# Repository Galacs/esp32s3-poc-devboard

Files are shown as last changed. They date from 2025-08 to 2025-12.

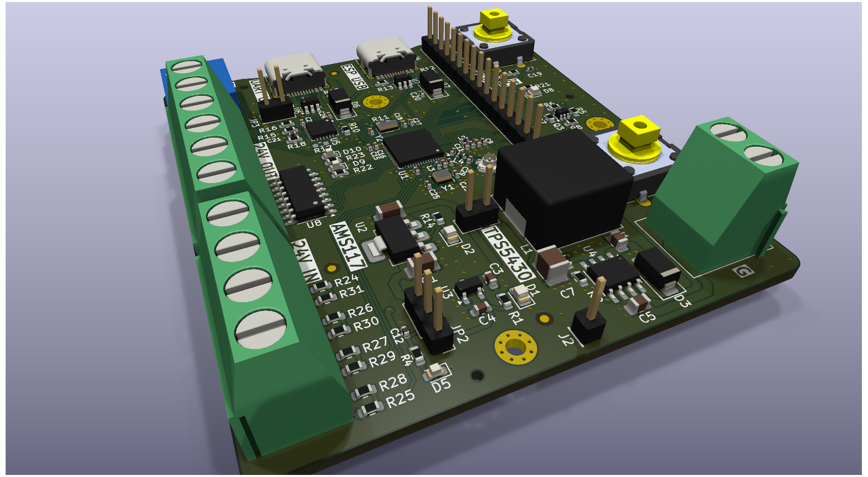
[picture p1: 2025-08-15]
docs/esp32s3-poc-devboard-render.png

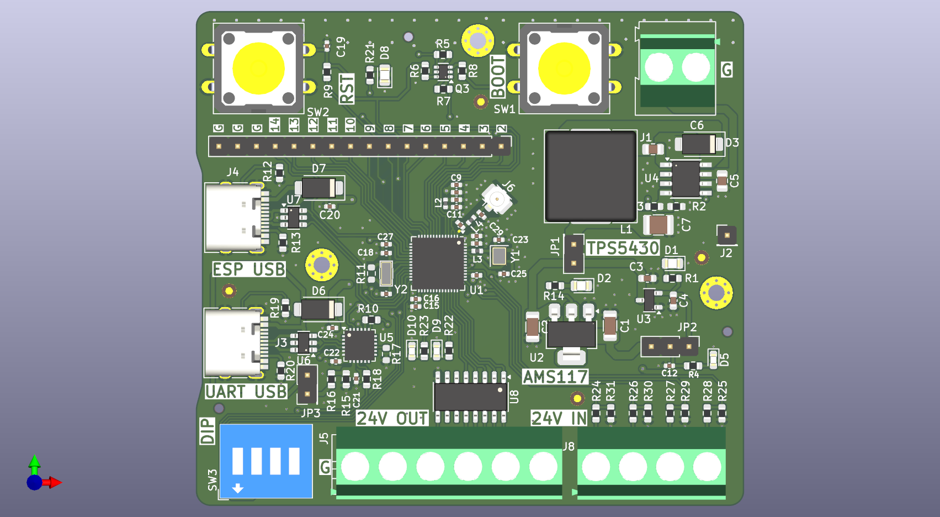
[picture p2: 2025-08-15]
docs/esp32s3-poc-devboard-top.png

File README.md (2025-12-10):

# ESP32-S3 POC/Devboard

ESP32-S3 based PoC board made to test step-down power supply design, 24v level shifter, crystal circuits and RF circuit

## IC List

- ESP32-S3Fx (main MCU)
- CP2102 (USB to UART)
- TPS5430 (step-down converter)
- AP2112K & XC6206 (3v3 LDOs)
- ULN2003A (transistor array)

## Top preview

esp32s3-poc-devboard-top

## Preview 3d render

esp32s3-poc-devboard-render

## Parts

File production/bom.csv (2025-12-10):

Designator | Footprint | Quantity | Value | LCSC Part #
C10, C11, C16, C17, C18 | 0402 | 5 | 0u1 | C307331
C12, C20, C22, C24, C8 | 0402 | 5 | 10u | C15525
C13 | 0402 | 1 | 10n | C15195
C14, C15, C19, C9 | 0402 | 4 | 1u | C52923
C21, C3, C30, C4 | 0603 | 4 | 1u | C15849
C23, C25 | 0402 | 2 | 12p | C1547
C26, C27 | 0402 | 2 | 20p | C1554
C28, C29 | 0402 | 2 | 1p2 | C76899
C5 | 0805 | 1 | 10u | C440198
C6 | 0805 | 1 | 10n | C1710
C7 | 1206 | 1 | 47u | C96123
D1, D2, D8 | 0805 | 3 | GREEN | C2297
D10 | 0603 | 1 | RED | C2286
D11, D12, D13, D14 | D_SOD-123 | 4 | BZT52B3V3 | C19077392
D3, D6, D7 | D_SMA | 3 | D_Schottky | C22452
D5, D9 | 0603 | 2 | WHITE | C2290
J3, J4 | USB_C_Receptacle_HRO_TYPE-C-31-M-12 | 2 | USB_C_Receptacle_USB2.0_14P | C393939
J6 | U.FL_Hirose_U.FL-R-SMT-1_Vertical | 1 | Conn_Coaxial | C88374
L1 | L_SXN_SMDRI127 | 1 | 100u | C10150
L2, L4 | 0402 | 2 | 2n7 | C412269
L3 | 0402 | 1 | 24n | C167472
Q3 | SOT-363_SC-70-6 | 1 | MMDT5551 | C41375116
R1, R12, R13, R14, R19, R20, R21, R22, R23, R24, R26, R27, R28, R4 | 0603 | 14 | 5k1 | C23186
R10 | 0603 | 1 | 470 | C23179
R18 | 0603 | 1 | 1k | C21190
R2 | 0603 | 1 | 4k7 | C23162
R25, R29, R30, R31 | 0603 | 4 | 750 | C23241
R3, R5, R7, R9 | 0603 | 4 | 10k | C25804
R6, R8 | 0603 | 2 | 0 | C21189
U1 | QFN-56-1EP_7x7mm_P0.4mm_EP5.6x5.6mm | 1 | ESP32-S3FH4R2 | C3013940
U3 | SOT-23-3 | 1 | XC6206P332MR-G | C5446
U4 | TI_SO-PowerPAD-8_ThermalVias | 1 | TPS5430DDA | C9864
U5 | SOT-23-5 | 1 | AP2112K-3.3 | C51118
U6, U7 | SOT-23-6 | 2 | USBLC6-2SC6 | C7519
U8 | SOIC-16_3.9x9.9mm_P1.27mm | 1 | ULN2003A | C7512
U9 | QFN-28-1EP_5x5mm_P0.5mm_EP3.35x3.35mm | 1 | CP2102-GMR | C6568
Y1 | Crystal_SMD_2016-4Pin_2.0x1.6mm | 1 | 48M | C7206306
Y2 | Crystal_SMD_3215-2Pin_3.2x1.5mm | 1 | 32k768 | C32346

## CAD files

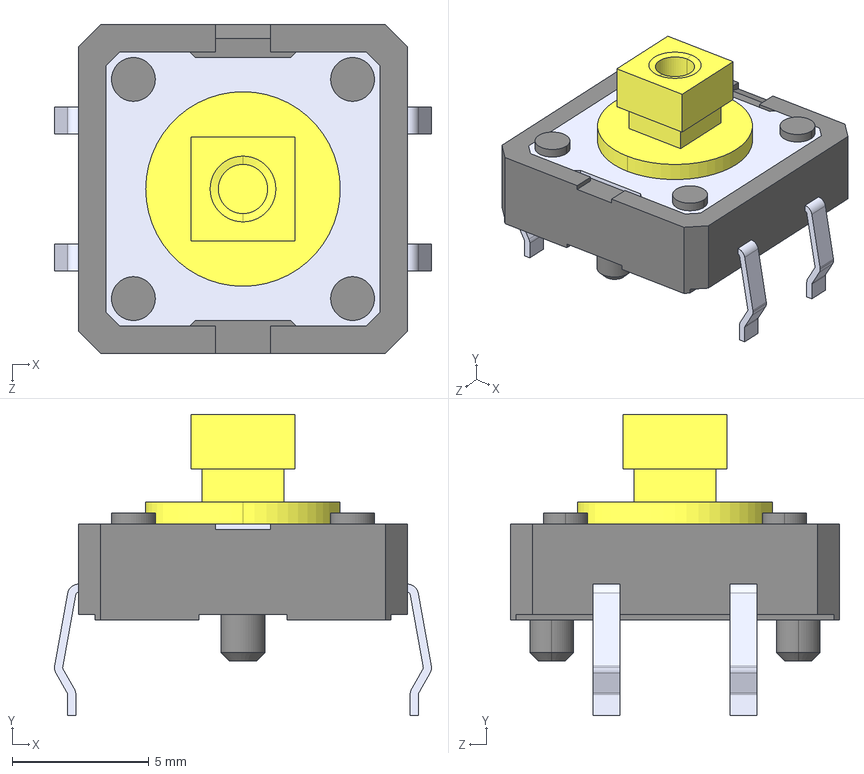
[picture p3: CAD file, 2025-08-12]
external_step/B3F-4055.STEP
13.8 x 11.0 x 12.0 mm

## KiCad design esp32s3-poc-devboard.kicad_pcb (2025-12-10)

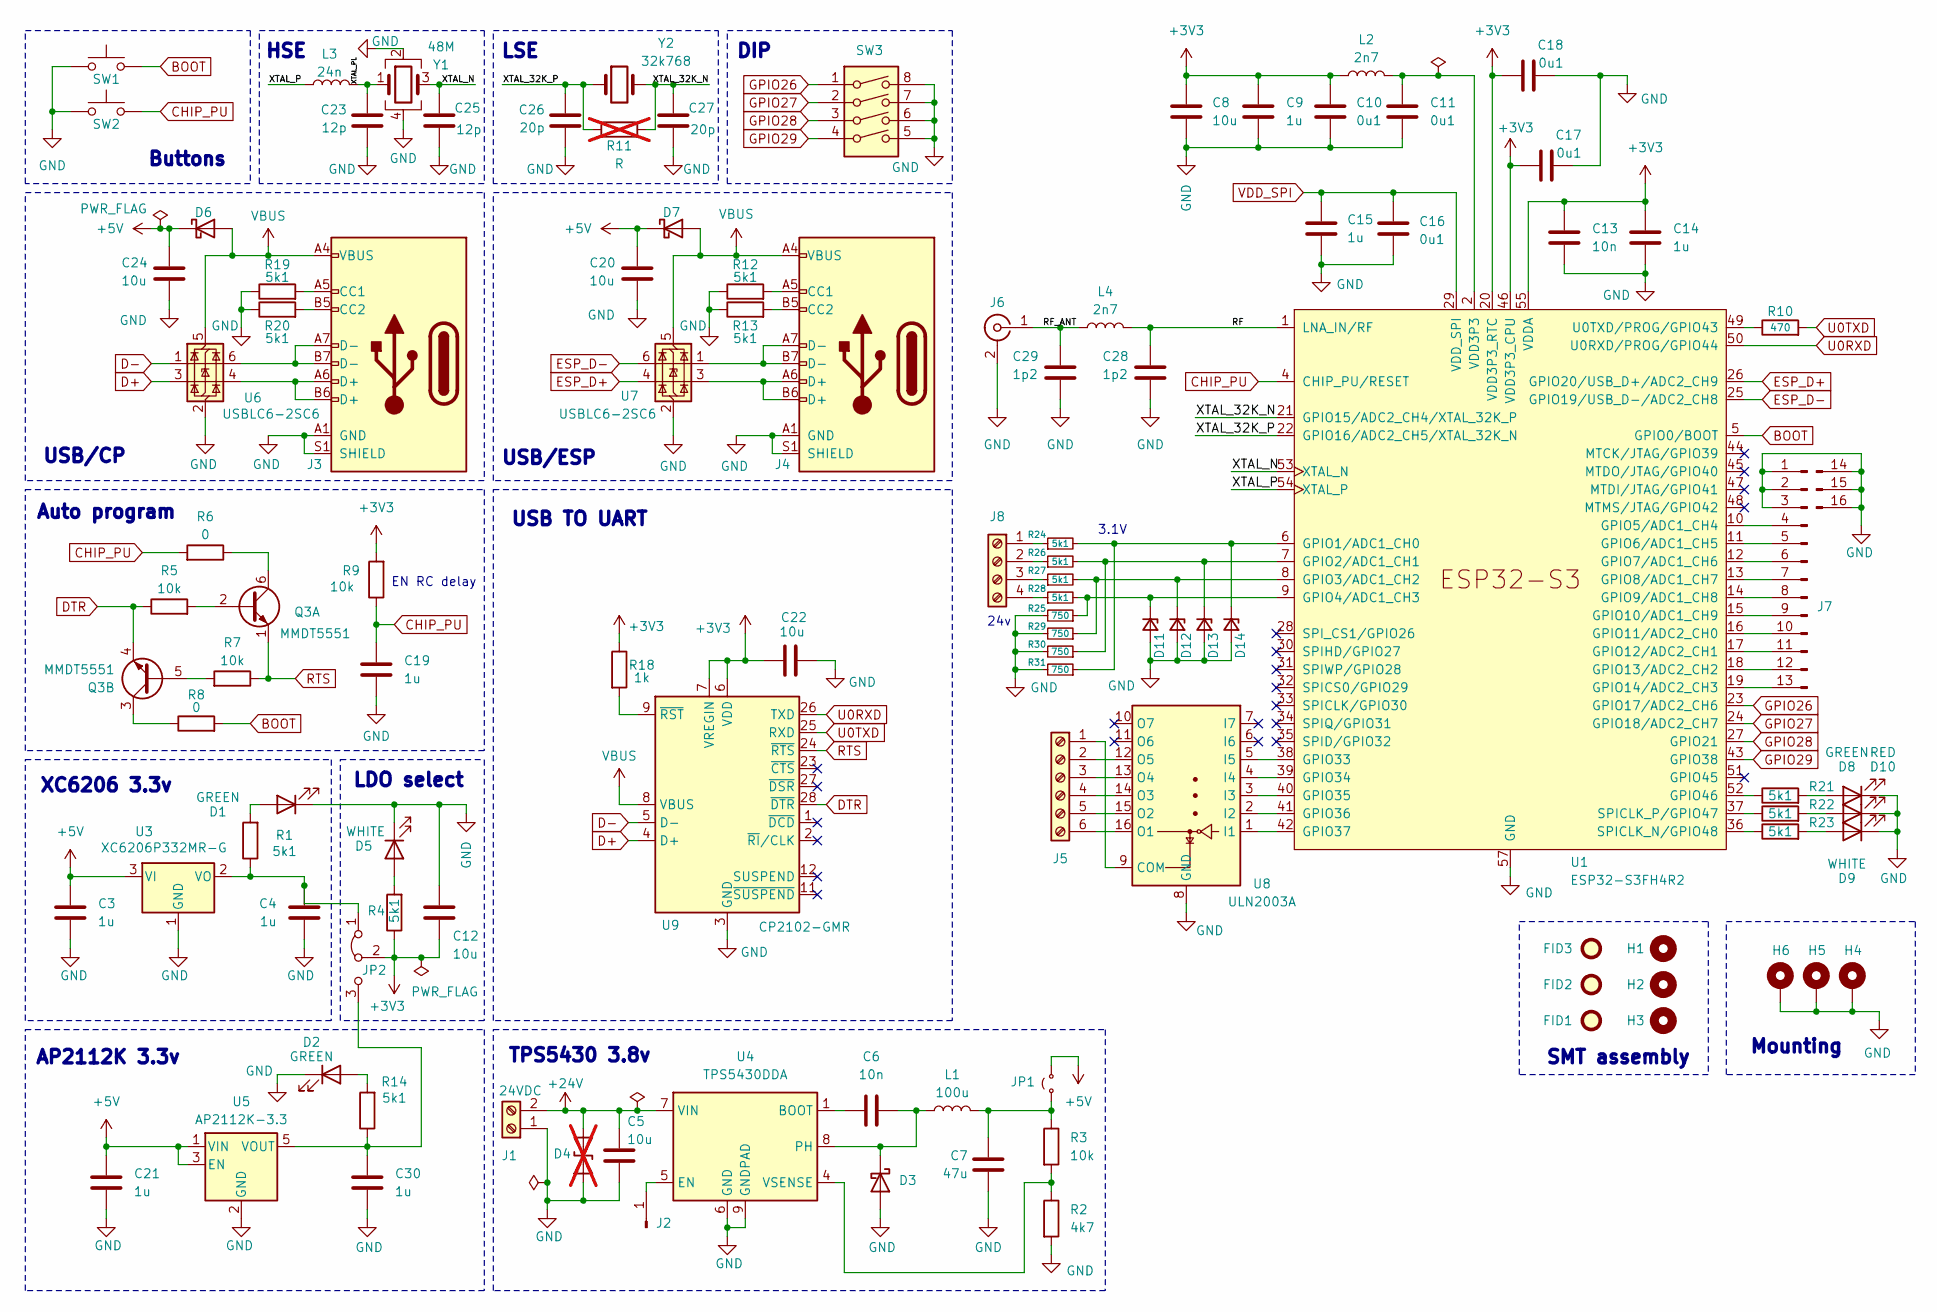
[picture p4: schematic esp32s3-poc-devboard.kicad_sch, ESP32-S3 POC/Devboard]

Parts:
C3, C4, C21, C30: 1u; C_0603_1608Metric; Manufacturer Part Number CL10A105KB8NNNC; JLCPCB Part # C15849
C5: 10u; C_0805_2012Metric; Manufacturer Part Number GRM21BR61H106KE43L; JLCPCB Part # C440198
C6: 10n; C_0805_2012Metric; Manufacturer Part Number CL21B103KBANNNC; JLCPCB Part # C1710
C7: 47u; C_1206_3216Metric; Manufacturer Part Number CL31A476MPHNNNE; JLCPCB Part # C96123
C8, C12, C20, C22, C24: 10u; C_0402_1005Metric; Manufacturer Part Number CL05A106MQ5NUNC; JLCPCB Part # C15525
C9, C14, C15, C19: 1u; C_0402_1005Metric; Manufacturer Part Number CL05A105KA5NQNC; JLCPCB Part # C52923
C10, C11, C16, C17, C18: 0u1; C_0402_1005Metric; Manufacturer Part Number CL05B104KB54PNC; JLCPCB Part # C307331
C13: 10n; C_0402_1005Metric; Manufacturer Part Number CL05B103KB5NNNC; JLCPCB Part # C15195
C23, C25: 12p; C_0402_1005Metric; Manufacturer Part Number 0402CG120J500NT; JLCPCB Part # C1547
C26, C27: 20p; C_0402_1005Metric; Manufacturer Part Number 0402CG200J500NT; JLCPCB Part # C1554
C28, C29: 1p2; C_0402_1005Metric; Manufacturer Part Number GJM1555C1H1R2WB01D; JLCPCB Part # C76899
D1, D2, D8: GREEN; LED_0805_2012Metric; Manufacturer Part Number KT-0805G; JLCPCB Part # C2297
D3, D6, D7: D_Schottky; D_SMA; Manufacturer Part Number SS54; JLCPCB Part # C22452
D4: D_TVS; not fitted
D5, D9: WHITE; LED_0603_1608Metric; Manufacturer Part Number KT-0603W; JLCPCB Part # C2290
D10: RED; LED_0603_1608Metric; Manufacturer Part Number KT-0603R; JLCPCB Part # C2286
D11, D12, D13, D14: BZT52B3V3; D_SOD-123; Manufacturer Part Number BZT52B3V3; JLCPCB Part # C19077392
FID1, FID2, FID3: Fiducial; Fiducial_1mm_Mask2mm
H1, H2, H3: MountingHole; ToolingHole_1.152mm
H4, H5, H6: MountingHole_Pad; MountingHole_2.2mm_M2_Pad_Via
J1: 24VDC; TerminalBlock_Altech_AK300-2_P5.00mm
J2: Conn_01x01_Pin; PinHeader_1x01_P2.54mm_Vertical
J3, J4: USB_C_Receptacle_USB2.0_14P; USB_C_Receptacle_HRO_TYPE-C-31-M-12; Manufacturer Part Number TYPE-C16PIN; JLCPCB Part # C393939
J5: Screw_Terminal_01x06; TerminalBlock_MaiXu_MX126-5.0-06P_1x06_P5.00mm
J6: Conn_Coaxial; U.FL_Hirose_U.FL-R-SMT-1_Vertical; Manufacturer Part Number U.FL-R-SMT-1(80); JLCPCB Part # C88374
J7: Conn_01x16_Pin; PinHeader_1x16_P2.54mm_Vertical
J8: Screw_Terminal_01x04; TerminalBlock_Altech_AK300-4_P5.00mm
JP1: Jumper_2_Small_Open; PinHeader_2x01_P2.54mm_Vertical
JP2: Jumper_3_Bridged12; PinHeader_1x03_P2.54mm_Vertical
L1: 100u; L_SXN_SMDRI127; Manufacturer Part Number SMDRI127-101MT; JLCPCB Part # C10150
L2, L4: 2n7; L_0402_1005Metric; Manufacturer Part Number LQW15AN2N7G80D; JLCPCB Part # C412269
L3: 24n; L_0402_1005Metric; Manufacturer Part Number LQW15AN24NG00D; JLCPCB Part # C167472
Q3: MMDT5551; SOT-363_SC-70-6; Manufacturer Part Number MMDT5551; JLCPCB Part # C41375116
R1, R4, R12, R13, R14, R19, R20, R21, R22, R23, R24, R26, R27, R28: 5k1; R_0603_1608Metric; Manufacturer Part Number 0603WAF5101T5E; JLCPCB Part # C23186
R2: 4k7; R_0603_1608Metric; Manufacturer Part Number 0603WAF4701T5E; JLCPCB Part # C23162
R3, R5, R7, R9: 10k; R_0603_1608Metric; Manufacturer Part Number 0603WAF1002T5E; JLCPCB Part # C25804
R6, R8: 0; R_0603_1608Metric; Manufacturer Part Number 0603WAF0000T5E; JLCPCB Part # C21189
R10: 470; R_0603_1608Metric; Manufacturer Part Number 0603WAF4700T5E; JLCPCB Part # C23179
R11: R; R_0603_1608Metric; not fitted
R18: 1k; R_0603_1608Metric; Manufacturer Part Number 0603WAF1001T5E; JLCPCB Part # C21190
R25, R29, R30, R31: 750; R_0603_1608Metric; Manufacturer Part Number 0603WAF7500T5E; JLCPCB Part # C23241
SW1, SW2: SW_Push; SW_SPST_Omron_B3F-40xx
SW3: SW_DIP_x04; SW_DIP_SPSTx04_Slide_9.78x12.34mm_W7.62mm_P2.54mm
U1: ESP32-S3FH4R2; QFN-56-1EP_7x7mm_P0.4mm_EP5.6x5.6mm; Manufacturer Part Number ESP32-S3FH4R2; JLCPCB Part # C3013940
U3: XC6206P332MR-G; SOT-23-3; Manufacturer Part Number XC6206P332MR-G; JLCPCB Part # C5446
U4: TPS5430DDA; TI_SO-PowerPAD-8_ThermalVias; Manufacturer Part Number TPS5430DDAR; JLCPCB Part # C9864
U5: AP2112K-3.3; SOT-23-5; Manufacturer Part Number AP2112K-3.3TRG1; JLCPCB Part # C51118
U6, U7: USBLC6-2SC6; SOT-23-6; Manufacturer Part Number USBLC6-2SC6; JLCPCB Part # C7519
U8: ULN2003A; SOIC-16_3.9x9.9mm_P1.27mm; Manufacturer Part Number ULN2003ADR; JLCPCB Part # C7512
U9: CP2102-GMR; QFN-28-1EP_5x5mm_P0.5mm_EP3.35x3.35mm; Manufacturer Part Number CP2102-GMR; JLCPCB Part # C6568
Y1: 48M; Crystal_SMD_2016-4Pin_2.0x1.6mm; Manufacturer Part Number R940000096; JLCPCB Part # C7206306
Y2: 32k768; Crystal_SMD_3215-2Pin_3.2x1.5mm; Manufacturer Part Number Q13FC13500004; JLCPCB Part # C32346

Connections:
+3V3: C8.1, C9.1, C10.1, C12.2, C13.1, C14.1, C17.1, C18.1, C22.2, JP2.2 (C), L2.1, R4.1, R9.2, R18.1, U1.20 (VDD3P3_RTC), U1.46 (VDD3P3_CPU), U1.55 (VDDA), U1.56 (VDDA), U9.6 (VDD), U9.7 (VREGIN)
+5V: C3.1, C20.1, C21.1, C24.1, D6.1 (K), D7.1 (K), JP1.2 (B), U3.3 (VI), U5.1 (VIN), U5.3 (EN)
+24V: C5.1, D4.2 (A2), J1.2, U4.7 (VIN)
/RF: C28.1, L4.2, U1.1 (LNA_IN/RF)
/RF_ANT: C29.1, J6.1 (In), L4.1
/XTAL_32K_N: C27.1, R11.2, U1.21 (GPIO15/ADC2_CH4/XTAL_32K_P), Y2.2
/XTAL_32K_P: C26.2, R11.1, U1.22 (GPIO16/ADC2_CH5/XTAL_32K_N), Y2.1
/XTAL_N: C25.1, U1.53 (XTAL_N), Y1.3
/XTAL_P: L3.1, U1.54 (XTAL_P)
/XTAL_PL: C23.2, L3.2, Y1.1
BOOT: R8.2, SW1.2, U1.5 (GPIO0/BOOT)
CHIP_PU: C19.1, R6.2, R9.1, SW2.2, U1.4 (CHIP_PU/RESET)
D+: U6.3 (I/O2), U9.4 (D+)
D-: U6.1 (I/O1), U9.5 (D-)
DTR: Q3.4 (E2), R5.1, U9.28 (~DTR)
ESP_D+: U1.26 (GPIO20/USB_D+/ADC2_CH9), U7.4 (I/O2)
ESP_D-: U1.25 (GPIO19/USB_D-/ADC2_CH8), U7.6 (I/O1)
GND: C3.2, C4.2, C5.2, C7.2, C8.2, C9.2, C10.2, C11.2, C12.1, C13.2, C14.2, C15.2, C16.2, C17.2, C18.2, C19.2, C20.2, C21.2, C22.1, C23.1, C24.2, C25.2, C26.1, C27.2, C28.2, C29.2, C30.2, D1.1 (K), D2.1 (K), D3.2 (A), D4.1 (A1), D5.1 (K), D8.1 (K), D9.1 (K), D10.1 (K), D11.2 (A), D12.2 (A), D13.2 (A), D14.2 (A), H4.1, H5.1, H6.1, J1.1, J3.A1 (GND), J3.A12 (GND), J3.B1 (GND), J3.B12 (GND), J3.S1 (SHIELD), J4.A1 (GND), J4.A12 (GND), J4.B1 (GND), J4.B12 (GND), J4.S1 (SHIELD), J6.2 (Ext), J7.1, J7.2, J7.3, J7.14, J7.15, J7.16, R2.2, R12.1, R13.1, R19.1, R20.1, R25.2, R29.2, R30.2, R31.2, SW1.1, SW2.1, SW3.5, SW3.6, SW3.7, SW3.8, U1.57 (GND), U3.1 (GND), U4.6 (GND), U4.9 (GNDPAD), U5.2 (GND), U6.2 (GND), U7.2 (GND), U8.8 (GND), U9.3 (GND), U9.29 (GND), Y1.2, Y1.4
GPIO26: SW3.1, U1.23 (GPIO17/ADC2_CH6)
GPIO27: SW3.2, U1.24 (GPIO18/ADC2_CH7)
GPIO28: SW3.3, U1.27 (GPIO21)
GPIO29: SW3.4, U1.43 (GPIO38)
unnamed: D1.2 (A), R1.2
unnamed: D2.2 (A), R14.2
unnamed: C6.1, D3.1 (K), L1.1, U4.8 (PH)
unnamed: D5.2 (A), R4.2
unnamed: D8.2 (A), R21.2
unnamed: D9.2 (A), R22.2
unnamed: D10.2 (A), R23.2
unnamed: D11.1 (K), R25.1, R28.2, U1.9 (GPIO4/ADC1_CH3)
unnamed: D12.1 (K), R27.2, R29.1, U1.8 (GPIO3/ADC1_CH2)
unnamed: D13.1 (K), R26.2, R30.1, U1.7 (GPIO2/ADC1_CH1)
unnamed: D14.1 (K), R24.2, R31.1, U1.6 (GPIO1/ADC1_CH0)
unnamed: J2.1, U4.5 (EN)
unnamed: J3.A5 (CC1), R19.2
unnamed: J3.B5 (CC2), R20.2
unnamed: J3.A6 (D+), J3.B6 (D+), U6.4 (I/O2)
unnamed: J3.A7 (D-), J3.B7 (D-), U6.6 (I/O1)
unnamed: J4.A5 (CC1), R12.2
unnamed: J4.B5 (CC2), R13.2
unnamed: J4.A6 (D+), J4.B6 (D+), U7.3 (I/O2)
unnamed: J4.A7 (D-), J4.B7 (D-), U7.1 (I/O1)
unnamed: J5.1, U8.9 (COM)
unnamed: J5.2, U8.12 (O5)
unnamed: J5.3, U8.13 (O4)
unnamed: J5.4, U8.14 (O3)
unnamed: J5.5, U8.15 (O2)
unnamed: J5.6, U8.16 (O1)
unnamed: J7.4, U1.10 (GPIO5/ADC1_CH4)
unnamed: J7.5, U1.11 (GPIO6/ADC1_CH5)
unnamed: J7.6, U1.12 (GPIO7/ADC1_CH6)
unnamed: J7.7, U1.13 (GPIO8/ADC1_CH7)
unnamed: J7.8, U1.14 (GPIO9/ADC1_CH8)
unnamed: J7.9, U1.15 (GPIO10/ADC1_CH9)
unnamed: J7.10, U1.16 (GPIO11/ADC2_CH0)
unnamed: J7.11, U1.17 (GPIO12/ADC2_CH1)
unnamed: J7.12, U1.18 (GPIO13/ADC2_CH2)
unnamed: J7.13, U1.19 (GPIO14/ADC2_CH3)
unnamed: J8.1, R24.1
unnamed: J8.2, R26.1
unnamed: J8.3, R27.1
unnamed: J8.4, R28.1
unnamed: C7.1, JP1.1 (A), L1.2, R3.1
unnamed: C4.1, JP2.1 (A), R1.1, U3.2 (VO)
unnamed: C30.1, JP2.3 (B), R14.1, U5.5 (VOUT)
unnamed: Q3.2 (B1), R5.2
unnamed: Q3.6 (C1), R6.1
unnamed: Q3.5 (B2), R7.2
unnamed: Q3.3 (C2), R8.1
unnamed: U1.38 (GPIO33), U8.5 (I5)
unnamed: U1.39 (GPIO34), U8.4 (I4)
unnamed: U1.40 (GPIO35), U8.3 (I3)
unnamed: U1.41 (GPIO36), U8.2 (I2)
unnamed: U1.42 (GPIO37), U8.1 (I1)
unnamed: R21.1, U1.52 (GPIO46)
unnamed: R23.1, U1.36 (SPICLK_N/GPIO48)
unnamed: R22.1, U1.37 (SPICLK_P/GPIO47)
unnamed: R10.1, U1.49 (U0TXD/PROG/GPIO43)
unnamed: C6.2, U4.1 (BOOT)
unnamed: R2.1, R3.2, U4.4 (VSENSE)
unnamed: R18.2, U9.9 (~RST)
RTS: Q3.1 (E1), R7.1, U9.24 (~RTS)
U0RXD: U1.50 (U0RXD/PROG/GPIO44), U9.26 (TXD)
U0TXD: R10.2, U9.25 (RXD)
VBUS: D6.2 (A), D7.2 (A), J3.A4 (VBUS), J3.A9 (VBUS), J3.B4 (VBUS), J3.B9 (VBUS), J4.A4 (VBUS), J4.A9 (VBUS), J4.B4 (VBUS), J4.B9 (VBUS), U6.5 (VBUS), U7.5 (VBUS), U9.8 (VBUS)
VDD3P3: C11.1, L2.2, U1.2 (VDD3P3), U1.3 (VDD3P3)
VDD_SPI: C15.1, C16.1, U1.29 (VDD_SPI)

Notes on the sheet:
AP2112K 3.3v
DIP
3.1V
HSE
EN RC delay
USB TO UART
Mounting
SMT assembly
Auto program
LSE
USB/ESP
LDO select
24v
Buttons
XC6206 3.3v
TPS5430 3.8v
USB/CP

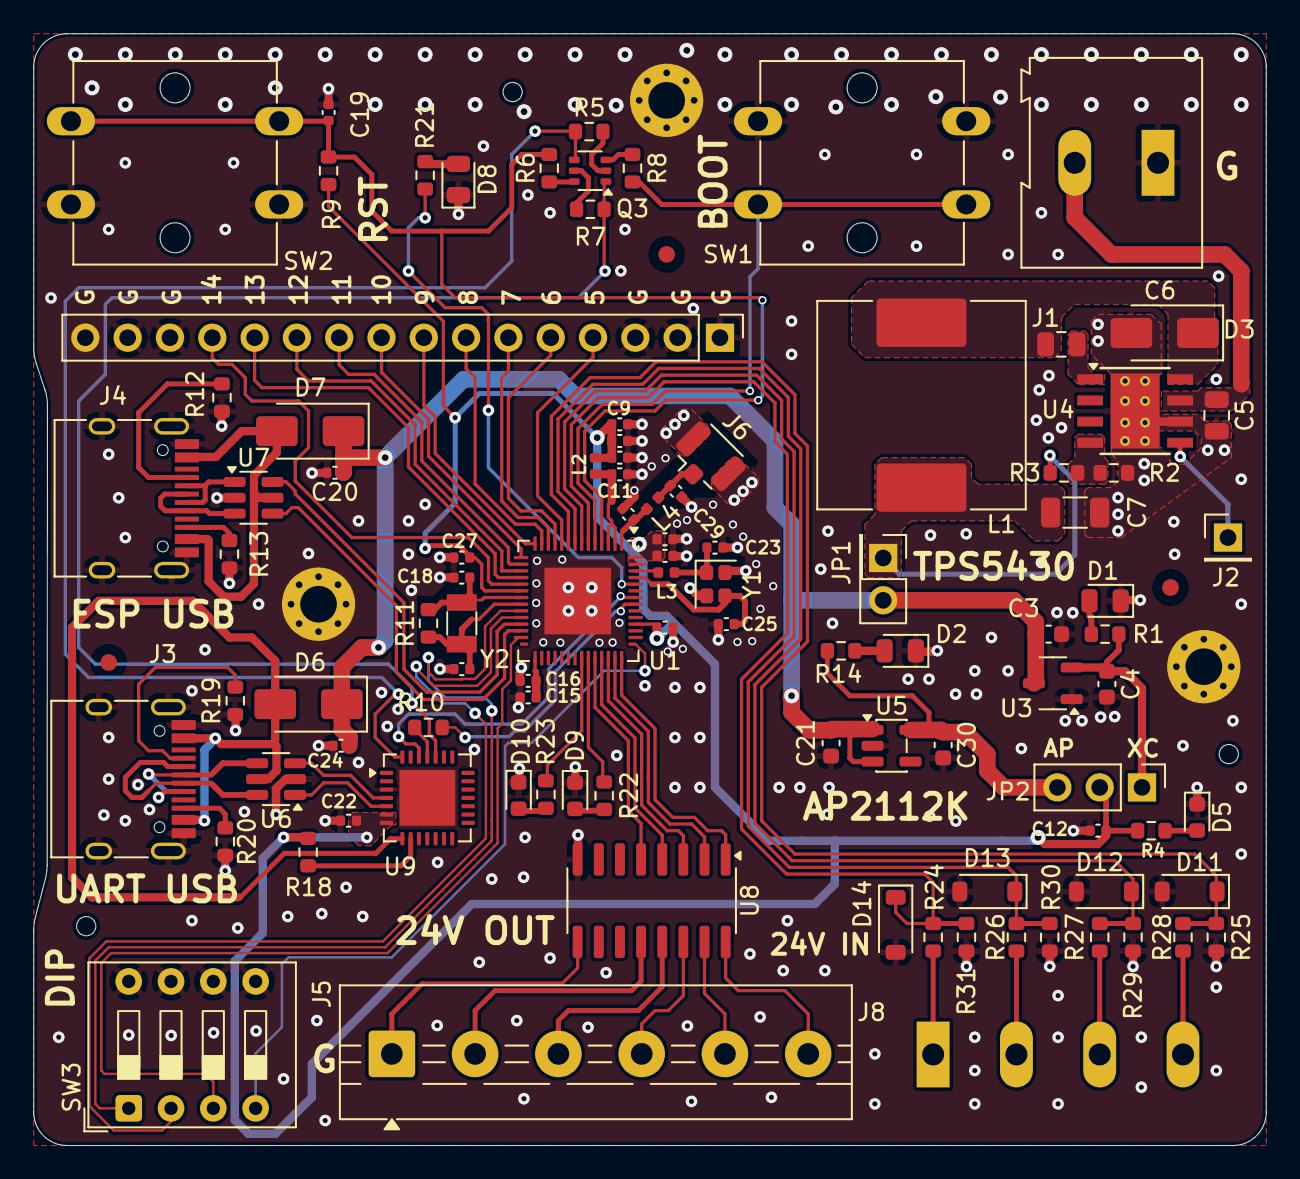
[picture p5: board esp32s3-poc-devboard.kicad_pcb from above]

Board: 4 copper layers, 74.0 x 66.8 mm, 106 parts (0 on the bottom side), 87 nets.

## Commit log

2025-07-16 AMS117 3.3v ldo
    [esp32s3-poc-devboard.kicad_sch]
2025-07-16 updated AMS117 3.3v ldo
    [esp32s3-poc-devboard.kicad_sch]
2025-07-16 add XC6206 3.3v ldo
    [esp32s3-poc-devboard.kicad_sch]
2025-07-16 add ldo selection jumper
    [esp32s3-poc-devboard.kicad_sch]
2025-07-16 add notes txt
    [esp32s3-poc-devboard.kicad_sch]
2025-07-16 changed pwr header to jumper
    [esp32s3-poc-devboard.kicad_sch]
2025-07-19 change to non-polarized capacitors
    [esp32s3-poc-devboard.kicad_sch]
2025-07-19 remove 3v3 jumper
    [esp32s3-poc-devboard.kicad_sch]
2025-07-19 TPS5430 3.8v smps
    [esp32s3-poc-devboard.kicad_sch]
2025-07-19 update TPS5430 location
    [esp32s3-poc-devboard.kicad_sch]
2025-07-20 add 3v3 power selection jumper
    [esp32s3-poc-devboard.kicad_sch]
2025-07-20 add mcu power strapping capacitors
    [esp32s3-poc-devboard.kicad_sch]
2025-07-20 add auto program circuit
    [esp32s3-poc-devboard.kicad_sch]
2025-07-20 add CP2102N usb to uart
    [esp32s3-poc-devboard.kicad_sch]
2025-07-20 add missing esp32 gnd
    [esp32s3-poc-devboard.kicad_sch]
2025-07-20 add rst/boot buttons
    [esp32s3-poc-devboard.kicad_sch]
2025-07-20 add vbus to avoid feeding usb from smps
    [esp32s3-poc-devboard.kicad_sch]
2025-07-20 fix some ground symbols orientation
    [esp32s3-poc-devboard.kicad_sch]
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2025-07-20 remove unnecessary resistor on U0RXD
    [esp32s3-poc-devboard.kicad_sch]
2025-07-22 add LSE and HSE crystals
    [esp32s3-poc-devboard.kicad_sch]
2025-07-28 add ULN2003A transistor array
    [esp32s3-poc-devboard.kicad_sch]
2025-07-28 fix ULN2003A orientation and add NCs
    [esp32s3-poc-devboard.kicad_sch]
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2025-08-03 add noconnect to esp32s3
    [esp32s3-poc-devboard.kicad_sch]
2025-08-03 add screw terminal input
    [esp32s3-poc-devboard.kicad_sch]
2025-08-03 add esp32 status led
    [esp32s3-poc-devboard.kicad_sch]
2025-08-03 add power flags for schematic erc
    [esp32s3-poc-devboard.kicad_sch]
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2025-08-11 add screw terminal 24v to 3.1v voltage divider
    [esp32s3-poc-devboard.kicad_sch]
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2025-08-11 add dip switch and resistor footprints
    [esp32s3-poc-devboard.kicad_sch]
2025-08-11 remove unconnected no connect
    [esp32s3-poc-devboard.kicad_sch]
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2025-08-11 add ordering info to BOM
    [esp32s3-poc-devboard.kicad_sch]
2025-08-11 fix internal flash/psram pins
    [esp32s3-poc-devboard.kicad_sch]
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2025-08-11 add pcb stackup and constraints
    [esp32s3-poc-devboard.kicad_pcb]
2025-08-12 import from schematic to pcb
    [esp32s3-poc-devboard.kicad_pcb]
2025-08-12 add or link missing 3d models
    [B3F-4055.STEP, esp32s3-poc-devboard.kicad_pcb]
2025-08-12 fix large screw terminal 3d model height
    [esp32s3-poc-devboard.kicad_pcb]
2025-08-12 add 24V symbol and netclass
    [esp32s3-poc-devboard.kicad_pcb, esp32s3-poc-devboard.kicad_sch]
2025-08-12 add missing R11 footprint
    [esp32s3-poc-devboard.kicad_pcb, esp32s3-poc-devboard.kicad_sch]
2025-08-12 add net classes colors
    [esp32s3-poc-devboard.kicad_pcb, esp32s3-poc-devboard.kicad_sch]
2025-08-12 initial rough pcb placement
    [esp32s3-poc-devboard.kicad_pcb, esp32s3-poc-devboard.kicad_sch]
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2025-08-12 refine usb diode placement
    [esp32s3-poc-devboard.kicad_pcb]
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2025-08-12 finish initial component placement
    [esp32s3-poc-devboard.kicad_pcb]
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2025-08-12 add inner ground layers
    [esp32s3-poc-devboard.kicad_pcb]
2025-08-12 add jlc tooling holes
    [esp32s3-poc-devboard.kicad_pcb]
2025-08-12 add M1 mounting holes
    [esp32s3-poc-devboard.kicad_pcb]
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2025-08-13 add uart traces routing
    [esp32s3-poc-devboard.kicad_pcb]
2025-08-13 add esp usb routing
    [esp32s3-poc-devboard.kicad_pcb]
2025-08-13 add usb to uart routing
    [esp32s3-poc-devboard.kicad_pcb]
2025-08-14 add ground return vias
    [esp32s3-poc-devboard.kicad_pcb]
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2025-08-14 add pin headers routing
    [esp32s3-poc-devboard.kicad_pcb]
2025-08-14 add dip switches routing
    [esp32s3-poc-devboard.kicad_pcb]
2025-08-14 add 24v O routing
    [esp32s3-poc-devboard.kicad_pcb]
2025-08-15 add 24v I routing
    [esp32s3-poc-devboard.kicad_pcb]
2025-08-15 add status leds routing
    [esp32s3-poc-devboard.kicad_pcb]
2025-08-15 add top layer gnd pour
    [esp32s3-poc-devboard.kicad_pcb]
2025-08-15 add +3v3 pwr routing
    [esp32s3-poc-devboard.kicad_pcb]
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2025-08-15 add rf lna in test point
    [esp32s3-poc-devboard.kicad_pcb]
2025-08-15 remove unused internal pads
    [esp32s3-poc-devboard.kicad_pcb]
2025-08-15 run drc and fixes
    [esp32s3-poc-devboard.kicad_pcb]
2025-08-15 add silkscreen text & logos
    [esp32s3-poc-devboard.kicad_pcb]
2025-08-15 fix top layer gnd
    [esp32s3-poc-devboard.kicad_pcb]
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2025-08-15 add missing +3v3 connection
    [esp32s3-poc-devboard.kicad_pcb]
2025-08-15 fix unconnected track
    [esp32s3-poc-devboard.kicad_pcb]
2025-08-15 fix various unconnected nets
    [esp32s3-poc-devboard.kicad_pcb]
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2025-12-10 schem: move 24v input to ADC pins
    [esp32s3-poc-devboard.kicad_sch]
2025-12-10 schem: add 3v3 protection diodes to adc pins
    [esp32s3-poc-devboard.kicad_sch]
2025-12-10 schem: update USBC symbol
    [esp32s3-poc-devboard.kicad_sch]
2025-12-10 schem: run and fix ERC
    [esp32s3-poc-devboard.kicad_sch]
2025-12-10 schem: update spare gpio pins
    [esp32s3-poc-devboard.kicad_sch]
2025-12-10 pcb: add new pin organisation
    [esp32s3-poc-devboard.kicad_pcb]
2025-12-10 schem: add fiducials, mounting and tooling holes
    [esp32s3-poc-devboard.kicad_sch]
2025-12-10 pcb: import fiducials, mounting and tooling holes
    [esp32s3-poc-devboard.kicad_pcb]
2025-12-10 pcb: run and fix DRC
    [esp32s3-poc-devboard.kicad_pcb]
2025-12-10 pcb: add missing usb 3d models
    [esp32s3-poc-devboard.kicad_pcb]
2025-12-10 pcb: place grid and drill origin
    [esp32s3-poc-devboard.kicad_pcb]
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2025-12-10 pcb: fix silkscreen to reflect pin changes
    [esp32s3-poc-devboard.kicad_pcb]
2025-12-10 pcb: add stitching vias
    [esp32s3-poc-devboard.kicad_pcb]
2025-12-10 schem: replace TPS5430 Cout with basic part
    [esp32s3-poc-devboard.kicad_pcb, esp32s3-poc-devboard.kicad_sch]
2025-12-10 pcb: change usb to uart to extended CP2102-GMR
    [esp32s3-poc-devboard.kicad_sch]
2025-12-10 pcb: update UART layout for new part
    [esp32s3-poc-devboard.kicad_pcb]
2025-12-10 schem: switched one ldo to AP2112K
    [esp32s3-poc-devboard.kicad_sch]
2025-12-10 pcb: add AP2112K routing
    [esp32s3-poc-devboard.kicad_pcb, esp32s3-poc-devboard.kicad_sch]
2025-12-10 pcb: remove unused pads
    [esp32s3-poc-devboard.kicad_pcb]
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
